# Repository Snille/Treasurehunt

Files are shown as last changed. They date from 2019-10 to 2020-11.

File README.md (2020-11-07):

# The Hunt for the Pirate coins

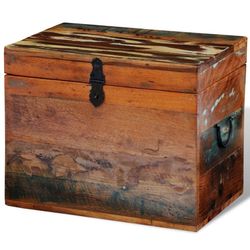
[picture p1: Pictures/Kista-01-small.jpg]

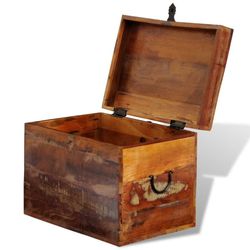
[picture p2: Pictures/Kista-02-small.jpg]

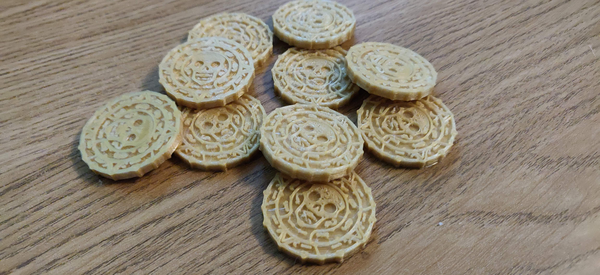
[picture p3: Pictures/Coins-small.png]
Pireate Coins


Here is a short video of the actual event. :)
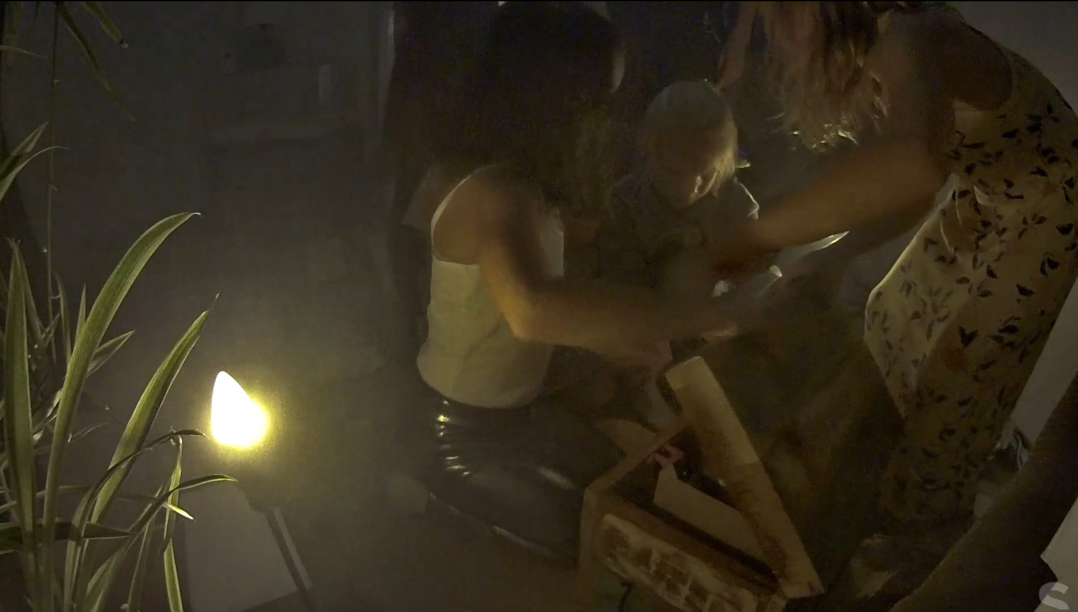
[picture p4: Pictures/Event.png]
The Event! (https://www.youtube.com/watch?v=7zYDTiijyEU "Jakten på Pitarmynten")


I made this event for my daughters 8:th birthday. The concept is copied from the theme of "Pirates of the Caribbean - The Cruise of the Black Perl". Basically the party guests have to find 100 [Pirate coins](https://www.thingiverse.com/thing:2936980)" to be able to "unlock" the Treasure Chest (containing candy).

Background story: During the summer, we had our yard dig up to add pluming to a new building. This lead to some strange finds in the ground. Among them where an old "chimney". So, I will use this memory to trigger some suspense when I give them a key "to something" that I found in the ground when we dug.
The key is for a small padlock that keeps the chest locked.

This is the plan:
The locked chest (locked with the padlock, they now have the key for) is setup in my office at home, I have prepared it so it will look really messy, paper-boxes everywhere, dirt on the floor and the chest will be chained to the wall so it can not be taken out of the room.

The door to the office will be closed and locked (it's usually open). But nothing suspicious will show from the "outside". 

when it's time for the hunt to begin, I start the start.py script on the raspberry pi installed inside the "Chest" (using SSH from my phone).
The script first "locks" the chest from the inside (using the servo that hatches on to the latch), starts the warm up of the smoke machine, pulls down the blinds over the window, sets the lighting to a prepared setting (turning on the "fire-like" lamps and lowering the ceiling light so that it shimmers), when the smoke machine is warm it fills the room with smoke and then changes the appearance of our [MagicMirror](https://forum.magicmirror.builders/topic/4563/snilles-magic-mirror-project?_=1603825886962) to a special "Treasure Hunt" profile and sets the text "The hunt for the pirate coins has begun!".

Then a preset playlist will be started on the SONOS player in the office at a specific volume level. This playlist just have one [track](https://www.youtube.com/watch?v=aylZ5naovxY) with the sounds of a wooden ship on the sea. You can also hear someone walking around.
While this is playing, from time to time, a laugh will be heard (played by the script). Hopefully after a while, the guests will start to noticing the sounds coming from the room. The problem is that it's locked.

They will of course ask for a key to the door, but I will just look surprised and say that the door should not be locked... Then give them the idea to "maybe" push a paper "under" the door and then use a stick (that I happens to have) to push the key out from the lock so that it falls down on the paper and they can pull it out from under the door using the paper. :)

When they manage to get in to the room, they are walking in to a room that is filled with smoke (I hacked the [smoke machine](https://www.kjell.com/se/produkter/hem-kontor-fritid/party-karaoke/rokmaskiner/rokmaskin-400-w-p22223) a bit to be able to control it with the Raspberry Pi from the script) and the lights are dimmed. Every time the random laugh is played a puff of smoke is produced. I also replaced the "on/off" switch on the wall with a "dummy" cover, so they can not change the lights. The "Ship sound" and the laughs are played pretty loud to make it more intimidating.

The treasure chest is placed on the flor and the "firey lights" are places beside the chest to make it look more "piraty" :), when they unlock the padlock and try to open the chest, a voice will say "To unlock the chest, you have to push at least 100 pirate coins in to the slot that opens up when trying to open the lid!". Now they will have to rummage through the card board boxes in the room to find all the coins. Every time they open (and close) the lid, the voice will tell how many coins they have found so far and the Magic Mirror will also display how many coins they have collected. A bit of smoke will be puffed out at every laugh when the lid closes.

When they finally have pushed all 100 coins in the chest, the lid will unlock (the servo will unlatch) and the lid can be opened. A message will be played saying "Congratulations!! You have found the 100 pirate coins, the chest is unlocked. I hope the candy is good!" and the room will then be "restored" to an office. Lights dims up to a normal and the blind is pulled back up (smoke will still be there of course... :)

The Chest electronics:

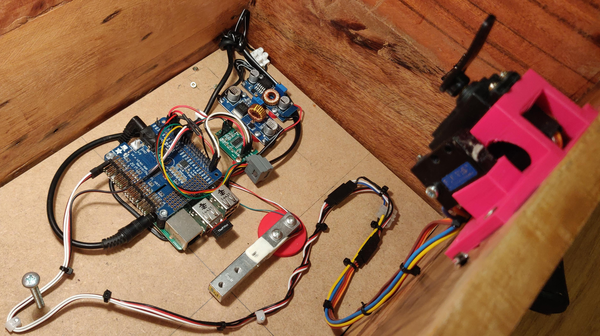
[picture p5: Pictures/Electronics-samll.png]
Electronics


This is the inside. The "outer" shelf is attached to the load cell and weigh the coins when they are pushed in from the front and the sides.

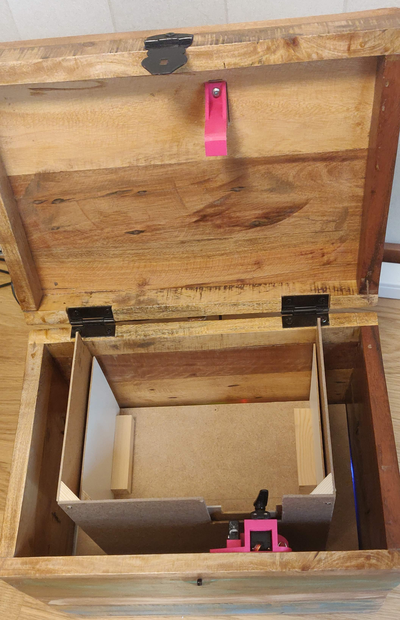
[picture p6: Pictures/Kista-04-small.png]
Open

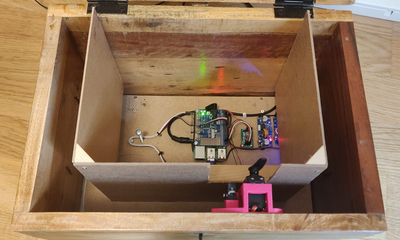
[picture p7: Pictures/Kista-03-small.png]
Electronics inside


The "hacked" Smoke Remote:

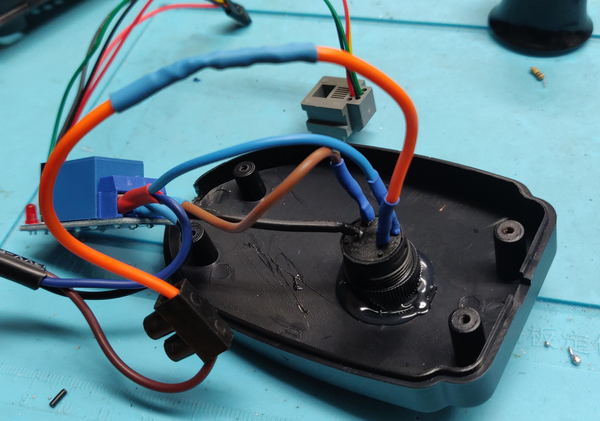
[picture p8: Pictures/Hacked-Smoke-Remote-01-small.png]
Remote

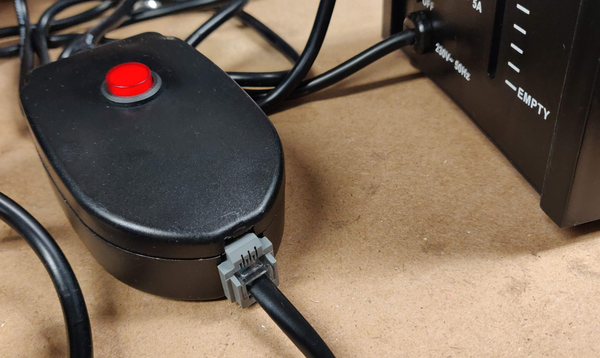
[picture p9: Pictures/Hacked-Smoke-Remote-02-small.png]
Remote


It's built around a 5kg "[Load Cell](https://www.ebay.co.uk/itm/Electronic-Balance-Weighing-Load-Cell-Sensor-5Kg-with-HX711-Module/162241279056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)" with a HX711 module a "[Treasure Chest](https://fyndgiganten.se/produkt/vidaxl-forvaringslada-i-atervunnet-tra/)" and the Pirates of the Caribbean treasure [Coin](https://www.thingiverse.com/thing:2936980).

When they lift and close the lid the first time the "Explain-01.wav" and then "Haha-01.wav" files are played. It continues to play even if the lid is opened and closed over and over until it's played in full. Then if they lift and close again the "Explain-02.wav" and "Haha-02.wav" are played the same way and if they lift and close a third time the "Explain-03.wav" and "Haha-03.wav" are played. Then it loops back to the first and so on, after every lift and close until some one starts to add in coins.

The participants has to find all the 100 (definable) pirate coins and push them in to the chest (lifting the lid the 15mm to get them in). Every time the lid closes the "Count-01.wav", "XX.wav" (depending of the number of coins added) and "Count-02.wav" will be played.

This will continue to happen until all coins inserted.

From time to time a laugh will be played and a puff of smoke will be deplyed during the whole session. 

When the correct amount of coins are inserted, the chest will unlock (the servo moves so the latch gets unhooked) and the last "Done-01.wav" will be played and the chest can now be opened.

PS: There is also a "secret" unlock button that can be hold to open the chest if needed. But it's of course only for testing and emergency's. :)

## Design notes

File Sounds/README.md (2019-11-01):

**The Treasure Hunt Sound Bank**

**I speak is in SWEDISH only!**

These sounds are created using this site: https://voicechanger.io/
I have used "Pitch Shift" @ -0.4 and "Giant Robot" @ 0.5 in that order.
Recorded with a standard "Web Cam". No fancy stuff... :)

Some sounds are not used in the program (yet)...

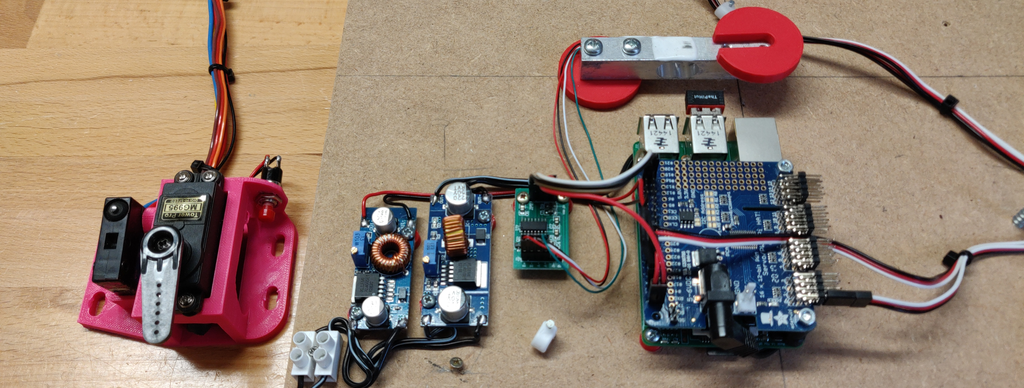
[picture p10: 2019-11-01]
Pictures/Electronics.png

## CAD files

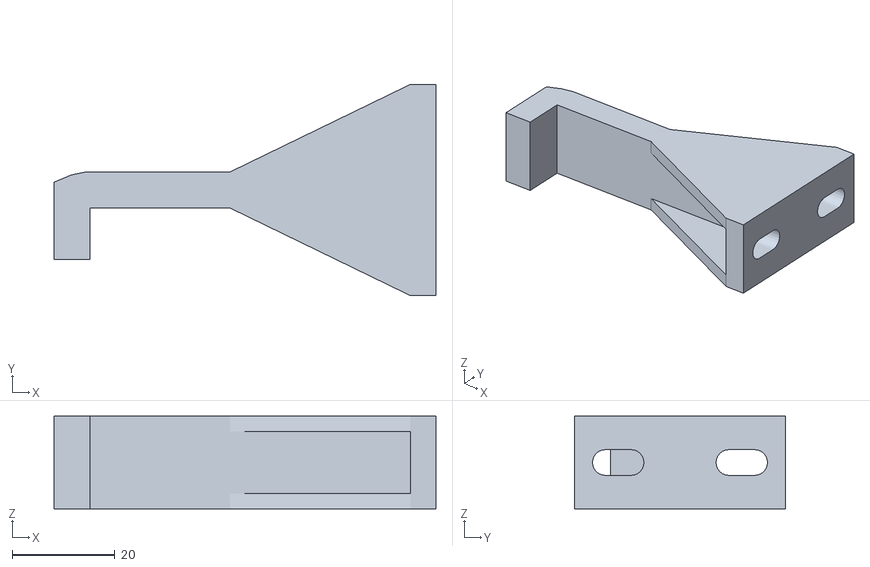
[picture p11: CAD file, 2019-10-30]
STLs/Hook-2.0 - sNi.stl
74.2 x 41.0 x 18.0

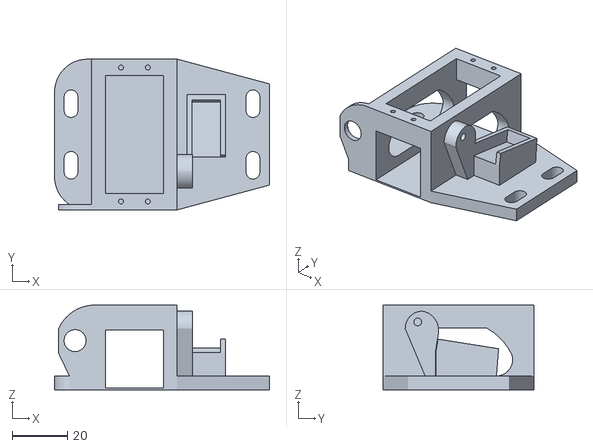
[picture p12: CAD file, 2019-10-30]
STLs/Holder-2.0 - sNi.stl
78.0 x 54.7 x 30.7

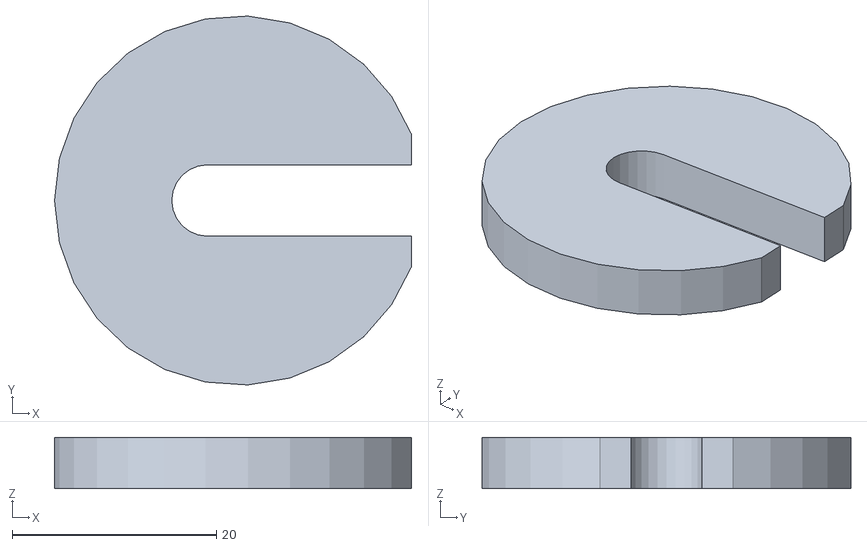
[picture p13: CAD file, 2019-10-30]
STLs/Spacer-1.0 - sNi.stl
35.0 x 36.2 x 5.00

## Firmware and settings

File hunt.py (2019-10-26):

#!/usr/bin/python2
#coding=utf-8

import time
import sys
import os
import os.path
from os import path
import RPi.GPIO as GPIO # Import Raspberry Pi GPIO library

# The directory where the sounds are located.
sounddir = "Sounds"

# HX711 Pinns used (GPIO number).
gpiopin1 = 5
gpiopin2 = 6

# Lid-button.
gpiopin3 = 3

# To emulate the HX711 set to True
EMULATE_HX711=False

# Coin ref = 827
# This coin is used: https://www.thingiverse.com/thing:2936980
# Printed in PLA with 20% infill.
referenceUnit = 827

if not EMULATE_HX711:
    import RPi.GPIO as GPIO
    from hx711 import HX711
else:
    from emulated_hx711 import HX711

# When control+C pressed!
def cleanAndExit():
    print("The hunt is over...")

    if not EMULATE_HX711:
        GPIO.cleanup()
    print("Have a nice day!")
    sys.exit()

# Pins to be used on PI.
hx = HX711(gpiopin1, gpiopin2)

# Format
hx.set_reading_format("MSB", "MSB")

# Make sure to change this at the top!
hx.set_reference_unit(referenceUnit)

hx.reset()
hx.tare()
print("Let the hunt begin!")

while True:
    try:
        # Make sure we don't get negative values.
        val = max(0, int(hx.get_weight(5)))

        # Do the logic here!
        fullpath = sounddir + "/" + str(val) + ".wav"
        # print(fullpath)
        if path.exists(fullpath):
            os.system("aplay -q " + fullpath)
        print("Collected coins so far: " + str(val))

        # Stop and reinitiate.
        hx.power_down()
        hx.power_up()

        # Wait a while.
        time.sleep(0.5)

    except (KeyboardInterrupt, SystemExit):
        cleanAndExit()

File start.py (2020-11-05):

#!/usr/bin/env python3
#coding=utf-8

import RPi.GPIO as GPIO
from hx711 import HX711
import time
import sys
import os
import os.path
from os import path
from adafruit_servokit import ServoKit
import random
import json
import urllib.request
import requests
import alsaaudio

## Servo information
# Set channels to the number of servo channels on your kit.
# 8 for FeatherWing, 16 for Shield/HAT/Bonnet.
kit = ServoKit(channels=16)
# Servo locking chest angle.
lockangle = 15
# Servo unlocking chest angle.
unlockangle = 130

## Coin stuff
# Coin weight number ratio in House: 855
ratio = 855
# Coin weight number ratio in Workshop: 827
#ratio = 827
# Coins to collect for the chest to open (100).
goal = 100
#goal = 3
# Set to 1 if it is ok to add more coins then specified in goal (chest opens when goal or higher is reached) otherwise it must be the exact goal number.
overgoalok = 1

## Button stuff
# Pin used for the lid switch. Low when the lid is closed.
lidpin = 23
# Secret open switch Pin.
secretpin = 24

## Smoke machine stuff.
# Smoke generator available (1 or 0).
usesmoke = 1
# When smoke machine is ready (warm). Set to 0 if not available on your smoke machine.
smokereadypin = 0
#smokereadypin = 24
# Smoke activation trigger When activated smoke is generated.
smokeactivatepin = 27
# Smoke machine warm up time in seconds (if the ready signal is not available).
smokewarmuptime = 150 # 2,5 minutes
#smokewarmuptime = 10 # 10 seconds
# Fill the room with smoke at start (1 or 0).
smokefill = 1
# How long (in seconds) to fill the room with smoke.
smokefilltime = 40 # 40 seconds
# Smoke "puff" time. The time in seconds the smoke machine will puff out new smoke during the "laughs".
smokepufftime = 2 # 1 second

## Sound settings
# Play the chest sounds (0 for no 1 for yes).
playsound = 1
# The directory where the sounds are located.
sounddir = "Sounds"
# Set Alsa "headphone jack" volume to "volume".
alsavolume = 100
# Start number for information sample (1, 2, 3).
info = 1

## MagicMirror stuff
# Post to the MagicMirror (1 = on or 0 = off).
mmpost = 1
# MagicMirror IP and port.
#mmip = "10.0.0.20" # Development MagicMirror.
#mmport = "8181"
mmip = "10.0.0.112" # Actual MagicMirror.
mmport = "8080"

# Time to wait before going back to the "normal" profile on the MagicMirror.
waittime = 300 # Five minutes.
#waittime = 30 # 30 seconds. 

# MagicMirror MMM-Remote-Control module commands to build on.
profilechange = "http://" + mmip + ":" + mmport + "/remote?action=NOTIFICATION&notification=CURRENT_PROFILE&payload="
showmodule = "http://" + mmip + ":" + mmport + "/remote?action=SHOW&module="
hidemodule = "http://" + mmip + ":" + mmport + "/remote?action=HIDE&module="

# MagicMirror treasure hunt Profile (sent to the MMM-Remote-Control module that changes profile via MMM-ProfileSwitcher).
startprofile = profilechange + "Skattjakt"
# MagicMirror treasure hunt win profile.
endprofile = profilechange + "Grattis"
# MagicMirror "normal" profile.
normalprofile = profilechange + "Louise"

# MagicMirror modules to show / hide.
# Shows and hides the IFTTT module at the end.
showiftttmodule = showmodule + "module_54_MMM-IFTTT"
hideiftttmodule = hidemodule + "module_54_MMM-IFTTT"

# Shows and hides: http://localhost/img/magicmirror/decoration/pirate-with-flag.png
showprestartmodule = showmodule + "module_15_MMM-ImageFit"
hideprestartmodule = hidemodule + "module_15_MMM-ImageFit"

# Shows and hides: http://localhost/img/magicmirror/decoration/coin-zoom-cropped.gif
showstartmodule = showmodule + "module_16_MMM-ImageFit"
hidestartmodule = hidemodule + "module_16_MMM-ImageFit"

# Shows and hides: http://localhost/img/magicmirror/decoration/coin-fall.gif
showcoinmodule1 = showmodule + "module_17_MMM-ImageFit"
hidecoinmodule1 = hidemodule + "module_17_MMM-ImageFit"

# Shows and hides: http://localhost/img/magicmirror/decoration/chest-on-coins.png
showcoinmodule2 = showmodule + "module_18_MMM-ImageFit"
hidecoinmodule2 = hidemodule + "module_18_MMM-ImageFit"

# Shows and hides the "everyone modules" below.
# Shows and hides: MMM-Modulebar
showmodulebar = showmodule + "module_59_MMM-Modulebar"
hidemodulebar = hidemodule + "module_59_MMM-Modulebar"

# Shows and hides: MMM-Sonos
showsonos = showmodule + "module_25_MMM-Sonos"
hidesonos = hidemodule + "module_25_MMM-Sonos"

# Shows and hides: MMM-HideAll
showhideall = showmodule + "module_61_MMM-HideAll"
hidehideall = hidemodule + "module_61_MMM-HideAll"

# Shows and hides: MMM-TouchNavigation
showtouchnavigation = showmodule + "module_62_MMM-TouchNavigation"
hidetouchnavigation = hidemodule + "module_62_MMM-TouchNavigation"

# Shows and hides: currentwather
showcurrentweather = showmodule + "module_38_currentweather"
hidecurrentweather = hidemodule + "module_38_currentweather"

# Shows and hides: weaterforcast
showweatherforecast = showmodule + "module_40_weatherforecast"
hideweatherforecast = hidemodule + "module_40_weatherforecast"

# Seconds to show the IFTTT messages on the MagicMirror (shows until time is up or a new message is sent).
# MagicMirror MMM-IFTTTs modules URL to use.
ifttturl = "http://" + mmip + ":" + mmport + "/IFTTT"
# Time for each message.
mmtime = 3600
# Time for the end message.
mmendtime = 300
# Size of the MagicMirror IFTTT message (small, medium, large).
mmsize = "large"

# IFTTT messages sent to the MagicMirror.
# Pre start message, displayed when the hunt begins and the chest locks.
# English: "The hunt for the pirate coins has begun!"
iftttprestartmessage = "Jakten på piratmynten har börjat!!"
# End message, displayed when the hunt is over and the chest unlocks.
# English: "Congratulations!! You have found the 100 pirate coins, the chest is unlocked. I hope the candy is good!"
iftttendmessage = "Grattis!! Ni har hittat 100 piratmynt! Kistan är upplåst, Hoppas godiset smakar!"
# Start message, displays when the lid is opened for the first time and until the first coin is added.
# English: "To unlock the chest, you have to push at least 100 pirate coins in to the slot that opens up when trying to open the lid!"
iftttstartmessage = "För att låsa upp kistan helt måste ni peta in minst 100 piratmynt genom glipan som blir när man försöker öppna kistlocket!"
# Repeated message when coins are added (two parts). The collected number of coins is inserted in between the messages.
# English: "You have found ", " pirate coins, keep on searching..."
iftttcoinmessage = ["Ni har hittat ", " av 100 piratmynt. Fortsätt leta..."]
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

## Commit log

2019-10-26 Added some more sounds. Tried a bit with the servos.
2019-10-29 Trying to add flip flop flr the secret open button.
    [start.py]
2019-10-30 Change name
    Changed the filename of last played sample.
2019-10-30 Added STLs and fixed a filname on the sounds.
    [Holder-2.0 - sNi.stl, Hook-2.0 - sNi.stl, Spacer-1.0 - sNi.stl]
2020-10-06 Added a testscript to test the buttons. Added lots of options in the start script.
2020-10-10 Fixed the HA integration...
    [start.py]
2020-10-24 Enabled real timer lenght.
2020-10-29 Fixed some bugs... :)
    [start.py]
2020-10-30 Added smoke machine test file. Fixed and tested smoke machine commands.
    [start.py, test-smoke.py]
2020-11-04 Small fixes, just visual stuff... :)
    [start.py]
